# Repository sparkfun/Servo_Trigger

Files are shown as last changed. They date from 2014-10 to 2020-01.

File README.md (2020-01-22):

SparkFun Servo Trigger
========================================

SparkFun Servo Trigger

[*SparkFun Servo Trigger (WIG-13118)*](https://www.sparkfun.com/products/13118)

The SparkFun Servo Trigger is a small robotics board that simplifies the control of hobby RC servo motors. 
When an external switch or logic signal changes state, the Servo Trigger is able to tell an attached servo motor to move from position A to position B. 
To use the Servo Trigger, you simply connect a hobby servo and a switch, then use the on-board potentiometers to adjust the start/stop positions and the transition time. 

Repository Contents
-------------------
* **/Docs** -  Programming notes
* **/Firmware** - Example firmware for running the Servo Trigger
* **/Hardware** - All Eagle design files (.brd, .sch)
* **/Production** - Test bed files and production panel files

License Information
-------------------
The hardware is released under [Creative Commons ShareAlike 4.0 International](https://creativecommons.org/licenses/by-sa/4.0/).
The code is beerware; if you see me (or any other SparkFun employee) at the local, and you've found our code helpful, please buy us a round!

Distributed as-is; no warranty is given.

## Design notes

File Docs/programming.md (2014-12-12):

# Some Notes About TINY84 Tools.

*For notes regarding getting in and out of the device using a JTAGICE3, see the /firmware/tool-notes.txt.  This file explains some of the finer points of using a Tiny Programmer (PGM-11801) and AVRDude for field reprogramming, most likely of files that were created using the IDE.*

## Prepping the Target

If you've been developing with SWD mode, you need to clear that fuse before the ISP will be active again.

Do this by loading and running an application in AVRStudio, then select "debug->quit and reenable ISP" to exit the debug session.  Simply hitting the stop button leaves it in SWD mode, which is incompatible with 

## Getting the Tools

I was using a SparkFun Tiny Programmer (PGM-11801).  Win64 Drivers were downloaded from the product page.

I soldered a female 2x3 header to the bottom of the programmer, and a male 2x3 to the top of the Servo Trigger.  When they plug in together, the servo trigger board will point away from the USB plug, so as not to interfere mechanically.

I got AVRDude in the WinAVR bundle from [sourceforge](http://sourceforge.net/projects/winavr/files/WinAVR/).  The latest release should be linked near the top of the page.  There are some notes there that the install clobbers your path - this appears to have been fixed, and my path only got longer.

The AVRDude docs are [hosted at nongnu.org](http://www.nongnu.org/avrdude/user-manual).

### Testing

You can invoke AVRDude in interactive mode to demonstrate that everything is working.

	>avrdude -t -c usbtiny -p t84

From there, the `sig` commands should return the chip device ID, or `read flash 0 10` should read 10 bytes of flash.

### Programming

The moment you've been waiting for:

	>avrdude -c usbtiny -p t84 -e -U flash:w:GccApplication1.hex

This also does a verification readback of the chip.

GccApplication1.hex is simply the hex file produced in the /debug/ or /release/ folders of the AVRStudio project.

### Verifying

Use interactive mode to `read flash 0 1000`.  It'll dump a bunch of hex.  If it's all 0xff's something went wrong.  You can alternately verify flash using the programming command line, but replacing the `:w:` with a `:v:`.

### Fuses 

Should you need them, the fuses are available from avrdude.

You can get to the fuses using the following names for the memories (via the read or dump commands):

* lfuse - lower fuse byte.
* hfuse - higher fuse byte.
* efuse - extended fuse byte.

The device I was expreimenting with during the composition of this document has fuses of:

* lower: 0x7f
* upper: 0xdf
* extended: 0xff

The definition of the fuse bits is hidden in section 19.2 of the datasheet.  In short, these are mostly the defaults - notable enabled features are: SPI programming enabled, and external resonator enabled.

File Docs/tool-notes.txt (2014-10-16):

Developed using Atmel Studio 6 (6.2.1153) and the JTAGICE3 debug box.
---------------------------------

Atmel DebugWire is cool, but a hassle to get started with.  I'm spending too much time messing 
with it, trying to navigate everything, so I'm capturing the tricks and secrets here.

Navigation
----------

The first trick is that there are two panels that interact.

The first of these is part of the project file - the tab in the editor named after the project 
(IE tab "GccApplication1," no file extension).  
There's a sub-tab there makred "tool". 

The second of these is the Device Programming dialog (Ctrl+shift+P), or the button with the 
chip & lightning on it.

The project->tool tab lists the debugger/programmer, and specifies the interface it's using, ISP or DW.

Chips come with ISP enabled and DW disabled, plus some other settings like default clock source & brownout settings.

In order for the Device Programming dialog to work, we have to be in ISP mode.

The First Time
--------------

With a brand new chip, set the project page to use ISP.

Open the programming dialog.  
	Enable the interface, the read the voltage and device ID.
	Go to the fuses tab, select clock source, etc as needed.  
	If you're moving to use DW, enable that fuse.
	Program the fuses for the target - it may request a target power cycle.
	Close the dialog.

Set the project page to use DW.
Build the application.
Start debugging by loading the applicaton (F5)
	Debug as normal - pausing, single stepping, breakpoints all work as expected.

If you're going to rebuild/reload without reconfiguring the fuses, etc, you can just quit using the stop menu button.

If you're going to reconfigure the chip, you need to use the "debug->disable DebugWIRE and close" menu item.  
Otherwise, the chip stays in DW mode, and you'll get the  "Got 0xc0, expected 0x00" error message.

When You Get Stuck
------------------

It plays out like this: Yesterday you were debugging, today you start and decide to go and check the 
chip config in the programming dialog.  
Nothing works, and the error details contain  "Got 0xc0, expected 0x00."

The trick to unjam it - set the project to DW, and restart the debug session (F5).  Once loaded, use 
the "debug->disable DW and close" to get out.  Now ISP can get in.

One other fatal thing:
--------------------

I think I set the fuses for an external clock that isn't present on the board...I can't seem to 
get in at all...still conjuring a solution.

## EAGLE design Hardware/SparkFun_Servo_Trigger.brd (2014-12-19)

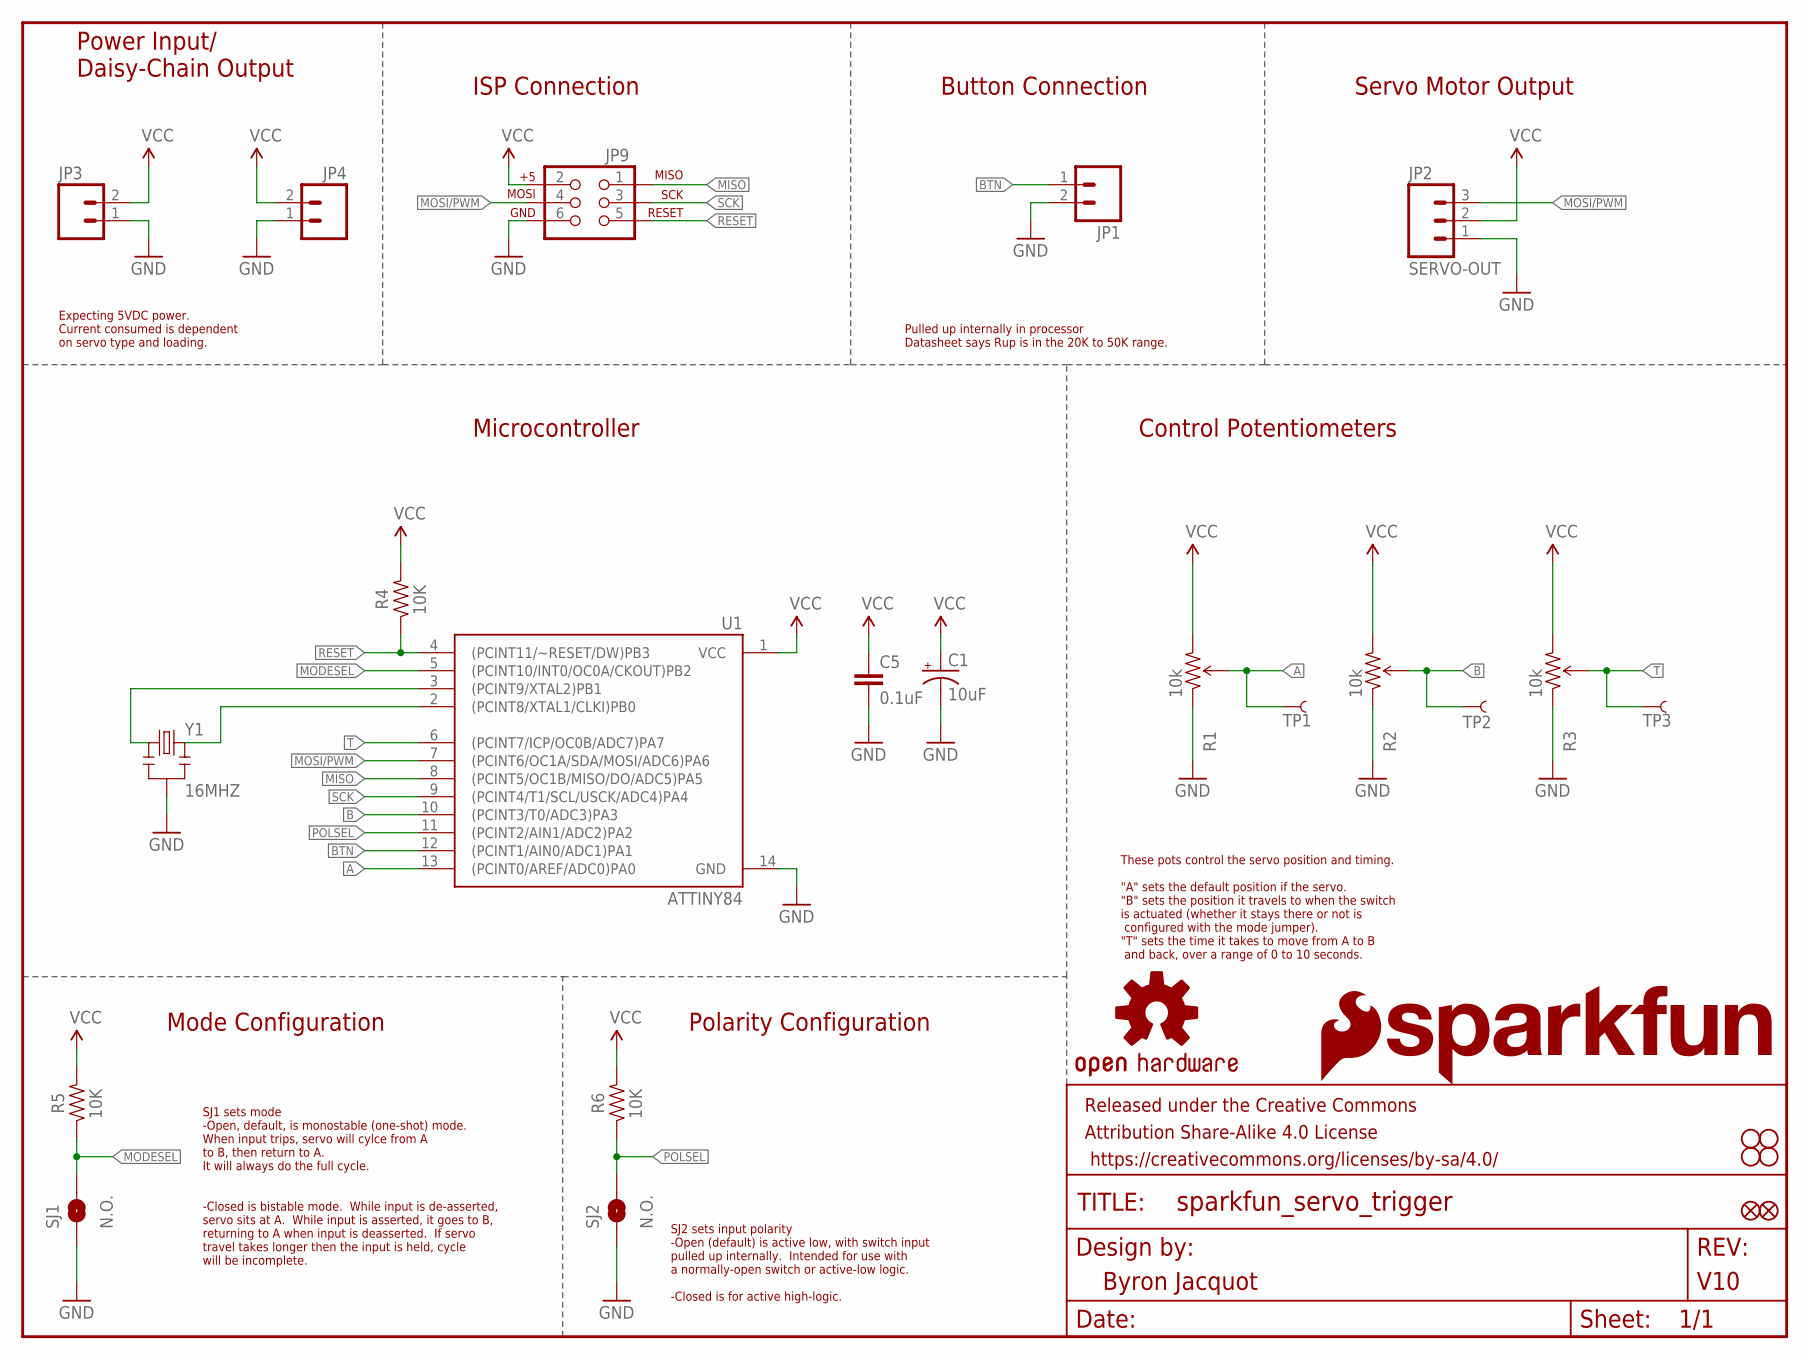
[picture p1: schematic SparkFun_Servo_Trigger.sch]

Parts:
C1: 10uF; EIA3216
C5: 0.1uF; 0603-CAP
FID1, FID2: FIDUCIAL1X2; FIDUCIAL-1X2
FRAME1: FRAME-LETTER; CREATIVE_COMMONS
JP1, JP3, JP4: M021X02_NO_SILK; 1X02_NO_SILK
JP2: SERVO-OUT; 1X03_NO_SILK
JP9: AVR_SPI_PRG_6PTH; 2X3
LOGO1: OSHW-LOGOM; OSHW-LOGO-M
LOGO2: SFE_LOGO_NAME.2_INCH; SFE_LOGO_NAME_.2
LOGO3: SFE_LOGO_FLAME.2_INCH; SFE_LOGO_FLAME_.2
R1, R2, R3: 10k; TRIMPOT_5MM
R4, R5, R6: 10K; 0603-RES
SJ1, SJ2: N.O.; PAD-JUMPER-2-NO_YES_SILK
STANDOFF1, STANDOFF2, STANDOFF3, STANDOFF4: STAND-OFF
TP1, TP2, TP3: TEST-POINT3X4; PAD.03X.04
U1: ATTINY84; SO14
Y1: 16MHZ; RESONATOR-SMD

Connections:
A: R1.B (WIPER), TP1.P$1, U1.13 ((PCINT0/AREF/ADC0)PA0)
B: R2.B (WIPER), TP2.P$1, U1.10 ((PCINT3/T0/ADC3)PA3)
BTN: JP1.1, U1.12 ((PCINT1/AIN0/ADC1)PA1)
GND: C1.C (-), C5.2, JP1.2, JP2.1, JP3.1, JP4.1, JP9.6, R1.A (CCW), R2.A (CCW), R3.A (CCW), SJ1.1, SJ2.1, U1.14 (GND), Y1.2
MISO: JP9.1, U1.8 ((PCINT5/OC1B/MISO/DO/ADC5)PA5)
MODESEL: R5.1, SJ1.2, U1.5 ((PCINT10/INT0/OC0A/CKOUT)PB2)
MOSI/PWM: JP2.3, JP9.4, U1.7 ((PCINT6/OC1A/SDA/MOSI/ADC6)PA6)
unnamed: U1.3 ((PCINT9/XTAL2)PB1), Y1.1
unnamed: U1.2 ((PCINT8/XTAL1/CLKI)PB0), Y1.3
POLSEL: R6.1, SJ2.2, U1.11 ((PCINT2/AIN1/ADC2)PA2)
RESET: JP9.5, R4.1, U1.4 ((PCINT11/~RESET/DW)PB3)
SCK: JP9.3, U1.9 ((PCINT4/T1/SCL/USCK/ADC4)PA4)
T: R3.B (WIPER), TP3.P$1, U1.6 ((PCINT7/ICP/OC0B/ADC7)PA7)
VCC: C1.A (+), C5.1, JP2.2, JP3.2, JP4.2, JP9.2, R1.C (CW), R2.C (CW), R3.C (CW), R4.2, R5.2, R6.2, U1.1 (VCC)

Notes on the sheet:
Power Input/ Daisy-Chain Output
ISP Connection
Control Potentiometers
Microcontroller
Button Connection
Servo Motor Output
Mode Configuration
Polarity Configuration
SJ1 sets mode -Open, default, is monostable (one-shot) mode. When input trips, servo will cylce from A to B, then return to A. It will always do the full cycle. -Closed is bistable mode. While input is de-asserted, servo sits at A. While input is asserted, it goes to B, returning to A when input is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
SJ2 sets input polarity -Open (default) is active low, with switch input pulled up internally. Intended for use with a normally-open switch or active-low logic. -Closed is for active high-logic.
Pulled up internally in processor Datasheet says Rup is in the 20K to 50K range.
Expecting 5VDC power. Current consumed is dependent on servo type and loading.
These pots control the servo position and timing. "A" sets the default position if the servo. "B" sets the position it travels to when the switch is actuated (whether it stays there or not is configured with the mode jumper). "T" sets the time it takes to move from A to B and back, over a range of 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

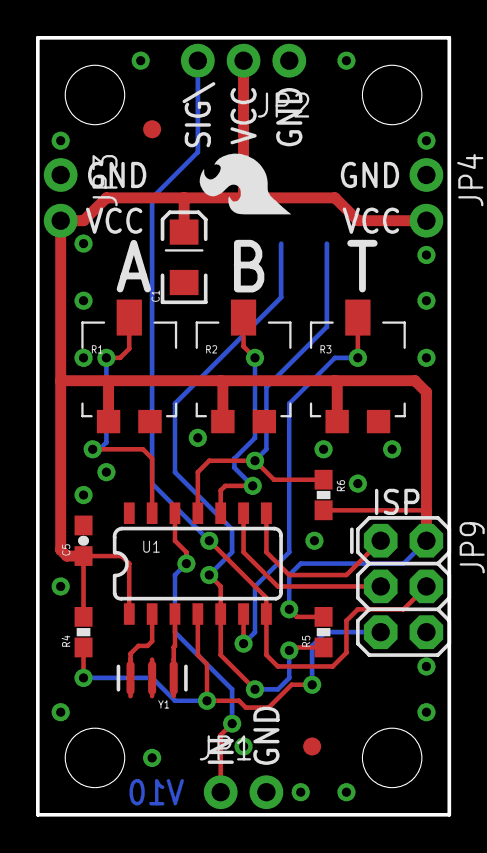
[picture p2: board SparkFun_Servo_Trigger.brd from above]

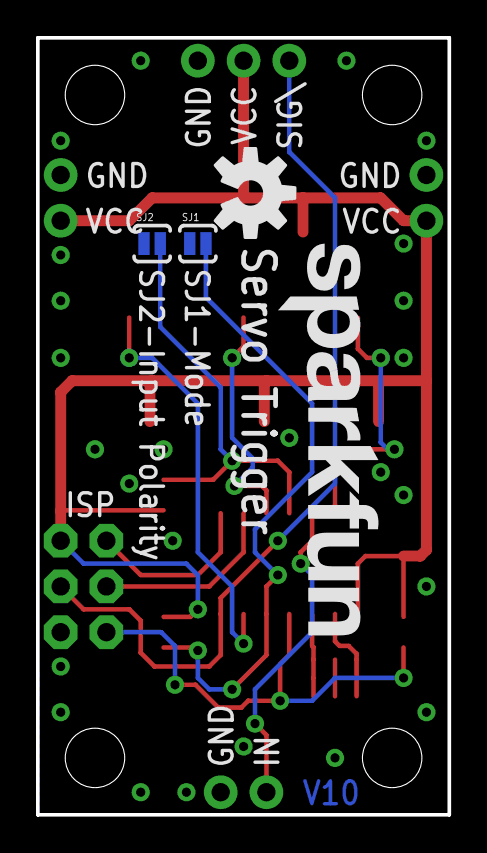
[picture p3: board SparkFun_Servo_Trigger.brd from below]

Board: 2 copper layers, 22.9 x 43.2 mm, 30 parts (7 on the bottom side), 14 nets.

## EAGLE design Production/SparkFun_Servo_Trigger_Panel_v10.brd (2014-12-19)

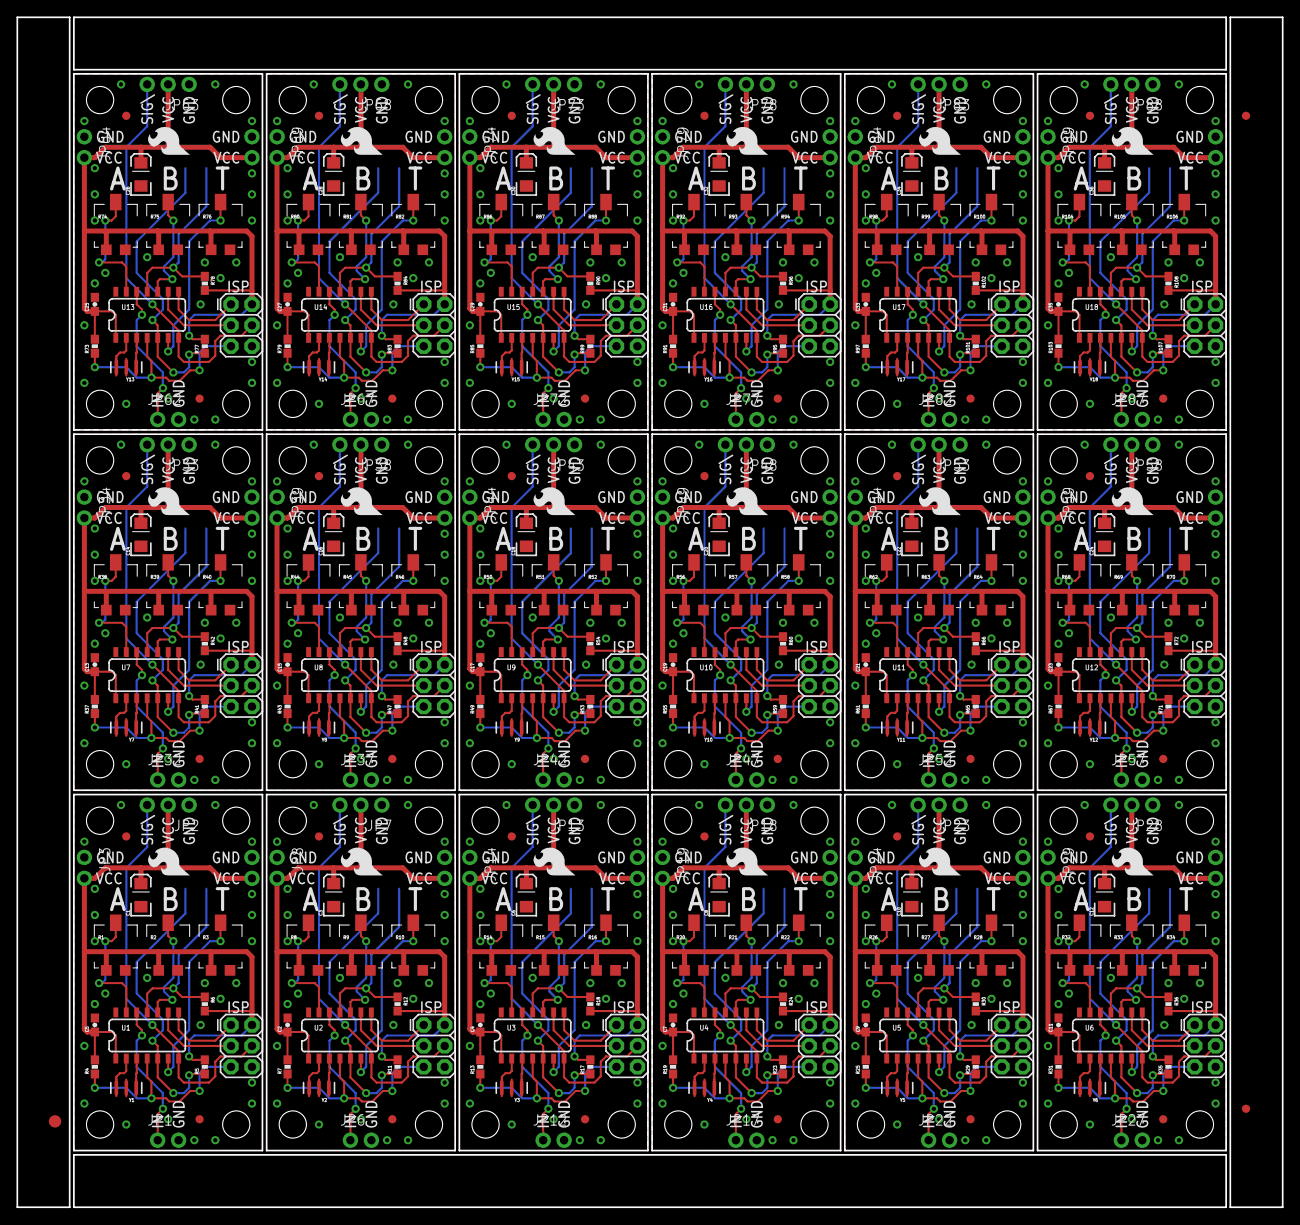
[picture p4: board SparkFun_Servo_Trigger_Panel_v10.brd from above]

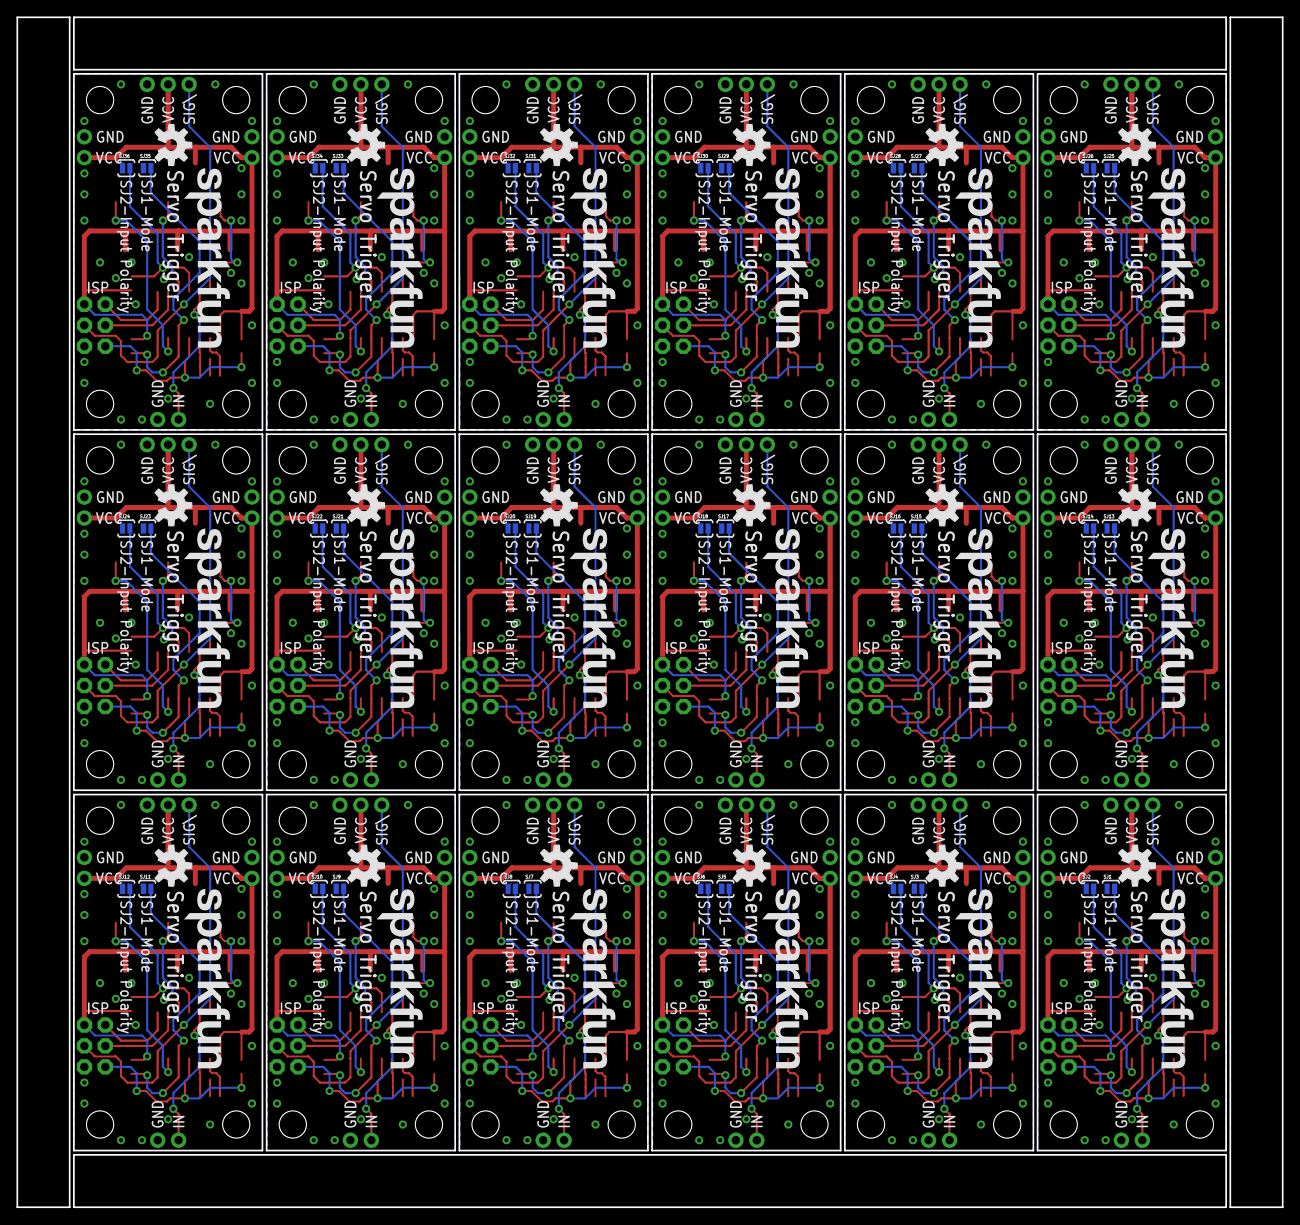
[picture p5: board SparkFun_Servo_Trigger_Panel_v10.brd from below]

Board: 2 copper layers, 153.4 x 144.3 mm, 525 parts (126 on the bottom side), 252 nets.

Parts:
C1, C3, C6, C8, C10, C12, C14, C16, C18, C20, C22, C24, C26, C28, C30, C32, C34, C36: 10uF; EIA3216
C2, C4, C5, C7, C9, C11, C13, C15, C17, C19, C21, C23, C25, C27, C29, C31, C33, C35: 0.1uF; 0603-CAP
E$1: FIDUCIAL-1.5X3
E$4, E$5: FIDUCIAL-1X2
FID1, FID2, FID3, FID4, FID5, FID6, FID7, FID8, FID9, FID10, FID11, FID12, FID13, FID14, FID15, FID16, FID17, FID18, FID19, FID20, FID21, FID22, FID23, FID24, FID25, FID26, FID27, FID28, FID29, FID30, FID31, FID32, FID33, FID34, FID35, FID36: FIDUCIAL1X2; FIDUCIAL-1X2
JP1, JP3, JP4, JP6, JP8, JP10, JP12, JP14, JP15, JP17, JP19, JP20, JP22, JP24, JP25, JP27, JP29, JP30, JP32, JP34, JP35, JP37, JP39, JP40, JP42, JP44, JP45, JP47, JP49, JP50, JP52, JP54, JP55, JP57, JP59, JP60, JP62, JP64, JP65, JP67, JP69, JP70, JP72, JP74, JP75, JP77, JP79, JP80, JP82, JP84, JP85, JP87, JP89, JP90: M021X02_NO_SILK; 1X02_NO_SILK
JP2, JP7, JP13, JP18, JP23, JP28, JP33, JP38, JP43, JP48, JP53, JP58, JP63, JP68, JP73, JP78, JP83, JP88: SERVO-OUT; 1X03_NO_SILK
JP5, JP9, JP11, JP16, JP21, JP26, JP31, JP36, JP41, JP46, JP51, JP56, JP61, JP66, JP71, JP76, JP81, JP86: 2X3
LOGO1, LOGO4, LOGO7, LOGO10, LOGO13, LOGO16, LOGO19, LOGO22, LOGO25, LOGO28, LOGO31, LOGO34, LOGO37, LOGO40, LOGO43, LOGO46, LOGO49, LOGO52: OSHW-LOGOM; OSHW-LOGO-M
LOGO2, LOGO5, LOGO8, LOGO11, LOGO14, LOGO17, LOGO20, LOGO23, LOGO26, LOGO29, LOGO32, LOGO35, LOGO38, LOGO41, LOGO44, LOGO47, LOGO50, LOGO53: SFE_LOGO_NAME.2_INCH; SFE_LOGO_NAME_.2
LOGO3, LOGO6, LOGO9, LOGO12, LOGO15, LOGO18, LOGO21, LOGO24, LOGO27, LOGO30, LOGO33, LOGO36, LOGO39, LOGO42, LOGO45, LOGO48, LOGO51, LOGO54: SFE_LOGO_FLAME.2_INCH; SFE_LOGO_FLAME_.2
R1, R2, R3, R8, R9, R10, R14, R15, R16, R20, R21, R22, R26, R27, R28, R32, R33, R34, R38, R39, R40, R44, R45, R46, R50, R51, R52, R56, R57, R58, R62, R63, R64, R68, R69, R70, R74, R75, R76, R80, R81, R82, R86, R87, R88, R92, R93, R94, R98, R99, R100, R104, R105, R106: 10k; TRIMPOT_5MM
R4, R5, R6, R7, R11, R12, R13, R17, R18, R19, R23, R24, R25, R29, R30, R31, R35, R36, R37, R41, R42, R43, R47, R48, R49, R53, R54, R55, R59, R60, R61, R65, R66, R67, R71, R72, R73, R77, R78, R79, R83, R84, R85, R89, R90, R91, R95, R96, R97, R101, R102, R103, R107, R108: 10K; 0603-RES
SJ1, SJ2, SJ3, SJ4, SJ5, SJ6, SJ7, SJ8, SJ9, SJ10, SJ11, SJ12, SJ13, SJ14, SJ15, SJ16, SJ17, SJ18, SJ19, SJ20, SJ21, SJ22, SJ23, SJ24, SJ25, SJ26, SJ27, SJ28, SJ29, SJ30, SJ31, SJ32, SJ33, SJ34, SJ35, SJ36: N.O.; PAD-JUMPER-2-NO_YES_SILK
STANDOFF1, STANDOFF2, STANDOFF3, STANDOFF4, STANDOFF5, STANDOFF6, STANDOFF7, STANDOFF8, STANDOFF9, STANDOFF10, STANDOFF11, STANDOFF12, STANDOFF13, STANDOFF14, STANDOFF15, STANDOFF16, STANDOFF17, STANDOFF18, STANDOFF19, STANDOFF20, STANDOFF21, STANDOFF22, STANDOFF23, STANDOFF24, STANDOFF25, STANDOFF26, STANDOFF27, STANDOFF28, STANDOFF29, STANDOFF30, STANDOFF31, STANDOFF32, STANDOFF33, STANDOFF34, STANDOFF35, STANDOFF36, STANDOFF37, STANDOFF38, STANDOFF39, STANDOFF40, STANDOFF41, STANDOFF42, STANDOFF43, STANDOFF44, STANDOFF45, STANDOFF46, STANDOFF47, STANDOFF48, STANDOFF49, STANDOFF50, STANDOFF51, STANDOFF52, STANDOFF53, STANDOFF54, STANDOFF55, STANDOFF56, STANDOFF57, STANDOFF58, STANDOFF59, STANDOFF60, STANDOFF61, STANDOFF62, STANDOFF63, STANDOFF64, STANDOFF65, STANDOFF66, STANDOFF67, STANDOFF68, STANDOFF69, STANDOFF70, STANDOFF71, STANDOFF72: STAND-OFF
TP1, TP2, TP3, TP4, TP5, TP6, TP7, TP8, TP9, TP10, TP11, TP12, TP13, TP14, TP15, TP16, TP17, TP18, TP19, TP20, TP21, TP22, TP23, TP24, TP25, TP26, TP27, TP28, TP29, TP30, TP31, TP32, TP33, TP34, TP35, TP36, TP37, TP38, TP39, TP40, TP41, TP42, TP43, TP44, TP45, TP46, TP47, TP48, TP49, TP50, TP51, TP52, TP53, TP54: TEST-POINT3X4; PAD.03X.04
U1, U2, U3, U4, U5, U6, U7, U8, U9, U10, U11, U12, U13, U14, U15, U16, U17, U18: ATTINY84; SO14
Y1, Y2, Y3, Y4, Y5, Y6, Y7, Y8, Y9, Y10, Y11, Y12, Y13, Y14, Y15, Y16, Y17, Y18: 16MHZ; RESONATOR-SMD

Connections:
A: R1.B, TP1.P$1, U1.13
A1: R8.B, TP4.P$1, U2.13
A2: R14.B, TP7.P$1, U3.13
A3: R20.B, TP10.P$1, U4.13
A4: R26.B, TP13.P$1, U5.13
A5: R32.B, TP16.P$1, U6.13
A6: R38.B, TP19.P$1, U7.13
A7: R44.B, TP22.P$1, U8.13
A8: R50.B, TP25.P$1, U9.13
A9: R56.B, TP28.P$1, U10.13
A10: R62.B, TP31.P$1, U11.13
A11: R68.B, TP34.P$1, U12.13
A12: R74.B, TP37.P$1, U13.13
A13: R80.B, TP40.P$1, U14.13
A14: R86.B, TP43.P$1, U15.13
A15: R92.B, TP46.P$1, U16.13
A16: R98.B, TP49.P$1, U17.13
A17: R104.B, TP52.P$1, U18.13
B: R2.B, TP2.P$1, U1.10
B1: R9.B, TP5.P$1, U2.10
B2: R15.B, TP8.P$1, U3.10
B3: R21.B, TP11.P$1, U4.10
B4: R27.B, TP14.P$1, U5.10
B5: R33.B, TP17.P$1, U6.10
B6: R39.B, TP20.P$1, U7.10
B7: R45.B, TP23.P$1, U8.10
B8: R51.B, TP26.P$1, U9.10
B9: R57.B, TP29.P$1, U10.10
B10: R63.B, TP32.P$1, U11.10
B11: R69.B, TP35.P$1, U12.10
B12: R75.B, TP38.P$1, U13.10
B13: R81.B, TP41.P$1, U14.10
B14: R87.B, TP44.P$1, U15.10
B15: R93.B, TP47.P$1, U16.10
B16: R99.B, TP50.P$1, U17.10
B17: R105.B, TP53.P$1, U18.10
BTN: JP1.1, U1.12
BTN1: JP6.1, U2.12
BTN2: JP12.1, U3.12
BTN3: JP17.1, U4.12
BTN4: JP22.1, U5.12
BTN5: JP27.1, U6.12
BTN6: JP32.1, U7.12
BTN7: JP37.1, U8.12
BTN8: JP42.1, U9.12
BTN9: JP47.1, U10.12
BTN10: JP52.1, U11.12
BTN11: JP57.1, U12.12
BTN12: JP62.1, U13.12
BTN13: JP67.1, U14.12
BTN14: JP72.1, U15.12
BTN15: JP77.1, U16.12
BTN16: JP82.1, U17.12
BTN17: JP87.1, U18.12
GND: C1.C, C5.2, JP1.2, JP2.1, JP3.1, JP4.1, JP9.6, R1.A, R2.A, R3.A, SJ1.1, SJ2.1, U1.14, Y1.2
GND1: C2.2, C3.C, JP5.6, JP6.2, JP7.1, JP8.1, JP10.1, R8.A, R9.A, R10.A, SJ3.1, SJ4.1, U2.14, Y2.2
GND2: C4.2, C6.C, JP11.6, JP12.2, JP13.1, JP14.1, JP15.1, R14.A, R15.A, R16.A, SJ5.1, SJ6.1, U3.14, Y3.2
GND3: C7.2, C8.C, JP16.6, JP17.2, JP18.1, JP19.1, JP20.1, R20.A, R21.A, R22.A, SJ7.1, SJ8.1, U4.14, Y4.2
GND4: C9.2, C10.C, JP21.6, JP22.2, JP23.1, JP24.1, JP25.1, R26.A, R27.A, R28.A, SJ9.1, SJ10.1, U5.14, Y5.2
GND5: C11.2, C12.C, JP26.6, JP27.2, JP28.1, JP29.1, JP30.1, R32.A, R33.A, R34.A, SJ11.1, SJ12.1, U6.14, Y6.2
GND6: C13.2, C14.C, JP31.6, JP32.2, JP33.1, JP34.1, JP35.1, R38.A, R39.A, R40.A, SJ13.1, SJ14.1, U7.14, Y7.2
GND7: C15.2, C16.C, JP36.6, JP37.2, JP38.1, JP39.1, JP40.1, R44.A, R45.A, R46.A, SJ15.1, SJ16.1, U8.14, Y8.2
GND8: C17.2, C18.C, JP41.6, JP42.2, JP43.1, JP44.1, JP45.1, R50.A, R51.A, R52.A, SJ17.1, SJ18.1, U9.14, Y9.2
GND9: C19.2, C20.C, JP46.6, JP47.2, JP48.1, JP49.1, JP50.1, R56.A, R57.A, R58.A, SJ19.1, SJ20.1, U10.14, Y10.2
GND10: C21.2, C22.C, JP51.6, JP52.2, JP53.1, JP54.1, JP55.1, R62.A, R63.A, R64.A, SJ21.1, SJ22.1, U11.14, Y11.2
GND11: C23.2, C24.C, JP56.6, JP57.2, JP58.1, JP59.1, JP60.1, R68.A, R69.A, R70.A, SJ23.1, SJ24.1, U12.14, Y12.2
GND12: C25.2, C26.C, JP61.6, JP62.2, JP63.1, JP64.1, JP65.1, R74.A, R75.A, R76.A, SJ25.1, SJ26.1, U13.14, Y13.2
GND13: C27.2, C28.C, JP66.6, JP67.2, JP68.1, JP69.1, JP70.1, R80.A, R81.A, R82.A, SJ27.1, SJ28.1, U14.14, Y14.2
GND14: C29.2, C30.C, JP71.6, JP72.2, JP73.1, JP74.1, JP75.1, R86.A, R87.A, R88.A, SJ29.1, SJ30.1, U15.14, Y15.2
GND15: C31.2, C32.C, JP76.6, JP77.2, JP78.1, JP79.1, JP80.1, R92.A, R93.A, R94.A, SJ31.1, SJ32.1, U16.14, Y16.2
GND16: C33.2, C34.C, JP81.6, JP82.2, JP83.1, JP84.1, JP85.1, R98.A, R99.A, R100.A, SJ33.1, SJ34.1, U17.14, Y17.2
GND17: C35.2, C36.C, JP86.6, JP87.2, JP88.1, JP89.1, JP90.1, R104.A, R105.A, R106.A, SJ35.1, SJ36.1, U18.14, Y18.2
MISO: JP9.1, U1.8
MISO1: JP5.1, U2.8
MISO2: JP11.1, U3.8
MISO3: JP16.1, U4.8
MISO4: JP21.1, U5.8
MISO5: JP26.1, U6.8
MISO6: JP31.1, U7.8
MISO7: JP36.1, U8.8
MISO8: JP41.1, U9.8
MISO9: JP46.1, U10.8
MISO10: JP51.1, U11.8
MISO11: JP56.1, U12.8
MISO12: JP61.1, U13.8
MISO13: JP66.1, U14.8
MISO14: JP71.1, U15.8
MISO15: JP76.1, U16.8
MISO16: JP81.1, U17.8
MISO17: JP86.1, U18.8
MODESEL: R5.1, SJ1.2, U1.5
MODESEL1: R11.1, SJ3.2, U2.5
MODESEL2: R17.1, SJ5.2, U3.5
MODESEL3: R23.1, SJ7.2, U4.5
MODESEL4: R29.1, SJ9.2, U5.5
MODESEL5: R35.1, SJ11.2, U6.5
MODESEL6: R41.1, SJ13.2, U7.5
MODESEL7: R47.1, SJ15.2, U8.5
MODESEL8: R53.1, SJ17.2, U9.5
MODESEL9: R59.1, SJ19.2, U10.5
MODESEL10: R65.1, SJ21.2, U11.5
MODESEL11: R71.1, SJ23.2, U12.5
MODESEL12: R77.1, SJ25.2, U13.5
MODESEL13: R83.1, SJ27.2, U14.5
MODESEL14: R89.1, SJ29.2, U15.5
MODESEL15: R95.1, SJ31.2, U16.5
MODESEL16: R101.1, SJ33.2, U17.5
MODESEL17: R107.1, SJ35.2, U18.5
MOSI/PWM: JP2.3, JP9.4, U1.7
MOSI/PWM1: JP5.4, JP7.3, U2.7
MOSI/PWM2: JP11.4, JP13.3, U3.7
MOSI/PWM3: JP16.4, JP18.3, U4.7
MOSI/PWM4: JP21.4, JP23.3, U5.7
MOSI/PWM5: JP26.4, JP28.3, U6.7
MOSI/PWM6: JP31.4, JP33.3, U7.7
MOSI/PWM7: JP36.4, JP38.3, U8.7
MOSI/PWM8: JP41.4, JP43.3, U9.7
MOSI/PWM9: JP46.4, JP48.3, U10.7
MOSI/PWM10: JP51.4, JP53.3, U11.7
MOSI/PWM11: JP56.4, JP58.3, U12.7
MOSI/PWM12: JP61.4, JP63.3, U13.7
MOSI/PWM13: JP66.4, JP68.3, U14.7
MOSI/PWM14: JP71.4, JP73.3, U15.7
MOSI/PWM15: JP76.4, JP78.3, U16.7
MOSI/PWM16: JP81.4, JP83.3, U17.7
MOSI/PWM17: JP86.4, JP88.3, U18.7
unnamed: U2.3, Y2.1
unnamed: U2.2, Y2.3
unnamed: U1.3, Y1.1
unnamed: U1.2, Y1.3
unnamed: U3.3, Y3.1
unnamed: U3.2, Y3.3
unnamed: U4.3, Y4.1
unnamed: U4.2, Y4.3
unnamed: U5.3, Y5.1
unnamed: U5.2, Y5.3
unnamed: U6.3, Y6.1
unnamed: U6.2, Y6.3
unnamed: U7.3, Y7.1
unnamed: U7.2, Y7.3
unnamed: U8.3, Y8.1
unnamed: U8.2, Y8.3
unnamed: U9.3, Y9.1
unnamed: U9.2, Y9.3
unnamed: U10.3, Y10.1
unnamed: U10.2, Y10.3
unnamed: U11.3, Y11.1
unnamed: U11.2, Y11.3
unnamed: U12.3, Y12.1
unnamed: U12.2, Y12.3
unnamed: U13.3, Y13.1
unnamed: U13.2, Y13.3
unnamed: U14.3, Y14.1
unnamed: U14.2, Y14.3
unnamed: U15.3, Y15.1
unnamed: U15.2, Y15.3
unnamed: U16.3, Y16.1
unnamed: U16.2, Y16.3
unnamed: U17.3, Y17.1
unnamed: U17.2, Y17.3
unnamed: U18.3, Y18.1
unnamed: U18.2, Y18.3
POLSEL: R6.1, SJ2.2, U1.11
POLSEL1: R12.1, SJ4.2, U2.11
POLSEL2: R18.1, SJ6.2, U3.11
POLSEL3: R24.1, SJ8.2, U4.11
POLSEL4: R30.1, SJ10.2, U5.11
POLSEL5: R36.1, SJ12.2, U6.11
POLSEL6: R42.1, SJ14.2, U7.11
POLSEL7: R48.1, SJ16.2, U8.11
POLSEL8: R54.1, SJ18.2, U9.11
POLSEL9: R60.1, SJ20.2, U10.11
POLSEL10: R66.1, SJ22.2, U11.11
POLSEL11: R72.1, SJ24.2, U12.11
POLSEL12: R78.1, SJ26.2, U13.11
POLSEL13: R84.1, SJ28.2, U14.11
POLSEL14: R90.1, SJ30.2, U15.11
POLSEL15: R96.1, SJ32.2, U16.11
POLSEL16: R102.1, SJ34.2, U17.11
POLSEL17: R108.1, SJ36.2, U18.11
RESET: JP9.5, R4.1, U1.4
RESET1: JP5.5, R7.1, U2.4
RESET2: JP11.5, R13.1, U3.4
RESET3: JP16.5, R19.1, U4.4
RESET4: JP21.5, R25.1, U5.4
RESET5: JP26.5, R31.1, U6.4
RESET6: JP31.5, R37.1, U7.4
RESET7: JP36.5, R43.1, U8.4
RESET8: JP41.5, R49.1, U9.4
RESET9: JP46.5, R55.1, U10.4
RESET10: JP51.5, R61.1, U11.4
RESET11: JP56.5, R67.1, U12.4
RESET12: JP61.5, R73.1, U13.4
RESET13: JP66.5, R79.1, U14.4
RESET14: JP71.5, R85.1, U15.4
RESET15: JP76.5, R91.1, U16.4
RESET16: JP81.5, R97.1, U17.4
RESET17: JP86.5, R103.1, U18.4
SCK: JP9.3, U1.9
SCK1: JP5.3, U2.9
SCK2: JP11.3, U3.9
SCK3: JP16.3, U4.9
SCK4: JP21.3, U5.9
SCK5: JP26.3, U6.9
SCK6: JP31.3, U7.9
SCK7: JP36.3, U8.9
SCK8: JP41.3, U9.9
SCK9: JP46.3, U10.9
SCK10: JP51.3, U11.9
SCK11: JP56.3, U12.9
SCK12: JP61.3, U13.9
SCK13: JP66.3, U14.9
SCK14: JP71.3, U15.9
SCK15: JP76.3, U16.9
SCK16: JP81.3, U17.9
SCK17: JP86.3, U18.9
T: R3.B, TP3.P$1, U1.6
T1: R10.B, TP6.P$1, U2.6
T2: R16.B, TP9.P$1, U3.6
T3: R22.B, TP12.P$1, U4.6
T4: R28.B, TP15.P$1, U5.6
T5: R34.B, TP18.P$1, U6.6
T6: R40.B, TP21.P$1, U7.6
T7: R46.B, TP24.P$1, U8.6
T8: R52.B, TP27.P$1, U9.6
T9: R58.B, TP30.P$1, U10.6
T10: R64.B, TP33.P$1, U11.6
T11: R70.B, TP36.P$1, U12.6
T12: R76.B, TP39.P$1, U13.6
T13: R82.B, TP42.P$1, U14.6
T14: R88.B, TP45.P$1, U15.6
T15: R94.B, TP48.P$1, U16.6
T16: R100.B, TP51.P$1, U17.6
T17: R106.B, TP54.P$1, U18.6
VCC: C1.A, C5.1, JP2.2, JP3.2, JP4.2, JP9.2, R1.C, R2.C, R3.C, R4.2, R5.2, R6.2, U1.1
VCC1: C2.1, C3.A, JP5.2, JP7.2, JP8.2, JP10.2, R7.2, R8.C, R9.C, R10.C, R11.2, R12.2, U2.1
VCC2: C4.1, C6.A, JP11.2, JP13.2, JP14.2, JP15.2, R13.2, R14.C, R15.C, R16.C, R17.2, R18.2, U3.1
VCC3: C7.1, C8.A, JP16.2, JP18.2, JP19.2, JP20.2, R19.2, R20.C, R21.C, R22.C, R23.2, R24.2, U4.1
VCC4: C9.1, C10.A, JP21.2, JP23.2, JP24.2, JP25.2, R25.2, R26.C, R27.C, R28.C, R29.2, R30.2, U5.1
VCC5: C11.1, C12.A, JP26.2, JP28.2, JP29.2, JP30.2, R31.2, R32.C, R33.C, R34.C, R35.2, R36.2, U6.1
VCC6: C13.1, C14.A, JP31.2, JP33.2, JP34.2, JP35.2, R37.2, R38.C, R39.C, R40.C, R41.2, R42.2, U7.1
VCC7: C15.1, C16.A, JP36.2, JP38.2, JP39.2, JP40.2, R43.2, R44.C, R45.C, R46.C, R47.2, R48.2, U8.1
VCC8: C17.1, C18.A, JP41.2, JP43.2, JP44.2, JP45.2, R49.2, R50.C, R51.C, R52.C, R53.2, R54.2, U9.1
VCC9: C19.1, C20.A, JP46.2, JP48.2, JP49.2, JP50.2, R55.2, R56.C, R57.C, R58.C, R59.2, R60.2, U10.1
VCC10: C21.1, C22.A, JP51.2, JP53.2, JP54.2, JP55.2, R61.2, R62.C, R63.C, R64.C, R65.2, R66.2, U11.1
VCC11: C23.1, C24.A, JP56.2, JP58.2, JP59.2, JP60.2, R67.2, R68.C, R69.C, R70.C, R71.2, R72.2, U12.1
VCC12: C25.1, C26.A, JP61.2, JP63.2, JP64.2, JP65.2, R73.2, R74.C, R75.C, R76.C, R77.2, R78.2, U13.1
VCC13: C27.1, C28.A, JP66.2, JP68.2, JP69.2, JP70.2, R79.2, R80.C, R81.C, R82.C, R83.2, R84.2, U14.1
VCC14: C29.1, C30.A, JP71.2, JP73.2, JP74.2, JP75.2, R85.2, R86.C, R87.C, R88.C, R89.2, R90.2, U15.1
VCC15: C31.1, C32.A, JP76.2, JP78.2, JP79.2, JP80.2, R91.2, R92.C, R93.C, R94.C, R95.2, R96.2, U16.1
VCC16: C33.1, C34.A, JP81.2, JP83.2, JP84.2, JP85.2, R97.2, R98.C, R99.C, R100.C, R101.2, R102.2, U17.1
VCC17: C35.1, C36.A, JP86.2, JP88.2, JP89.2, JP90.2, R103.2, R104.C, R105.C, R106.C, R107.2, R108.2, U18.1

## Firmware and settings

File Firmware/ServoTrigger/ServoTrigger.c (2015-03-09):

/*
 ServoTrigger.c
 
 Created: 7/3/2014 3:43:10 PM
 Author: byron.jacquot
 
 The Servo Trigger is a small board you can use to implement simple control 
 over hobby RC servos.  When an external switch or logic signal changes 
 state, the servo trigger causes the servo motor to move from  position A 
 to position B.  You also specify the time that the servo takes to make 
 the transition. 
 
 The code is designed to function primarily in the interrupt service routine
 for PWM1.  PWM hardware is configured to call the ISR at the start of the cycle
 when the output gets set high.  It then calculates and sets the pulse 
 width, and refreshes the ADC inputs.
 
 The main loop of the code is rather simple.  It sets up in I/O and
 PWM, then allows the interrupt to run, and puts the processor to 
 sleep in between.
 
 DEVELOPMENT TOOLS:
 This code was developed in Atmel Studio 6.2.1153.
 The build should also be compatible with avr-gcc & avrdude on the command line.
 
 BUILDING & CONFIGURATION:
 There are more possible state machines than can fit in memory all at once.
 2 FSMs can be present at a time - selected using the MODE solder jumper on the back
 of the PCB.  They are known as FSMA (jumper cleared - default) and FSMB (jumper soldered).
 
 The FSMs are selected by defining compile-time macros in the build scripts. 
 To change functions, find the -D directives, and set them to the names of the
 desired functions. 
 In AVRStudio, this is in the project tab->toolchain->AVR/GNU C compiler->symbols dialog. 
 In the command-line AVR-GCC, it's in the *.c->*.o rule in the makefile.
 
 You can select the FSMs for the two slots by changing the definition of the "FSMA" and
 "FSMB" macros.  These macros should be set to the name of the FSM function for the desired slot.
 There are several candidate FSM names:
  - bistableFSM
  - oneshotFSM
  - ctpFSM
  - togglingFSM
  - astableFSM
 
 See the product documentation for more details about each FSM.
 
 All of these FSMs are implemented in the source file - rather than building a bunch of 
 convoluted macros to include the right functions, we're taking advantage of the 
 linker-elision feature of GCC - functions that are never called will be omitted from the 
 output - you'll see the names in the "discarded sections" of the *.MAP file.  It's very
 dependent of compiling and linking with the right flags set.
 See this link for more info: https://gcc.gnu.org/ml/gcc-help/2003-08/msg00128.html
 
 
 If you want to implement your own FSM, there are a few things to know:
 - First, the FSMs operate on a phasor value to implement the ramp between A and B.
   The FSM function is invoked at the start of every PWM cycle, and it needs to 
   calculate and update the phasor value.  The phasor is 16-bits, and normalized 
   such that position A is always 0x0, and B is 0xffff.  The FSM updates the phasor.
 - The phasor will be translated for the actual A & B settings before it's applied.
 - There are helper routines:
     - calcDelta calculates how big a step is needed for a given setting of T
     - calcNextPhasor adds or subtracts the delta, and returns true when the phasor 
        reaches the end of the transit.
     - scalePhasor translates the 0 to 0xffff value to pulse width, in microseconds.
 
 */ 

#include <avr/io.h>
#include <avr/interrupt.h>
#include <avr/sleep.h>
#include <stdint.h>
#include <stdbool.h>

/* constant declarations */

// constants for the hardware interfaces
// Pots for positions A, B and time T.
// Numbers are ADC channels, not pins
static const uint8_t POTA_CHAN = 0;
static const uint8_t POTB_CHAN = 3;
static const uint8_t POTT_CHAN = 7;

// Pins for configuration solder jumpers
// "_A_" means in port A, "_B_" means in port B.
static const uint8_t POLSEL_A_MASK = 0x04;
static const uint8_t MODESEL_B_MASK = 0x04;

// Input pin for switch or trigger
// "_A_" means in port A
static const uint8_t TRIG_PIN_A_MASK = 0x02;

// Timing & ramp gen constants
// Pulse width = PWM_MIN_USEC + PWM_RANGE_USEC
// some servos have a wider range than others - 1 to 2 msec is safe for all tested so far.
// .7 to 2.3 msec will drive some farther, but will make others very unhappy, possibly grinding gears.

#ifdef SAFERANGE
// Some servos are *very* unhappy if pulses leave the 1 to 2 mSec range.  
// SAFERANGE constrains pulses to that range.
static const int32_t PWM_MIN_USEC   = 1000; // narrowest pulse is 1000 usec
static const int32_t PWM_RANGE_USEC = 1000; // diff between min and max PWM pulses.
#else
// some servos are less fragile/critical - if you want shorter/wider pulses, 
// you can enable these and adjust the values
static const int32_t PWM_MIN_USEC   = 700; // narrowest pulse is 700 usec
static const int32_t PWM_RANGE_USEC = 1600; // diff between min and max PWM pulses.
#endif


static const int32_t ADC_MAX        = 0x0000ffff; // ADC values are left-justified into 16-bits
static const int32_t PHASOR_MAX     = 0x0000ffff; // Phasor counts from 0 to 0xffff

// declare some constants for calculations
//
// Table of timing constants.
// These are looked up and added to the phasor on each pulse ISR.
// They are indexed & interpolated using the T pot.
//
// Each value was calc'd using the spreadsheet: translation.ods
//
// the formula per entry is
// value = PHASOR_MAX/pwm freq in Hz/desired time
// ie: increment = 0xffff/50/travel time
//
// Table is 17 entries long so we can do linear interpolation between
// the N and N+1th entries, indexed using 4 MSBs of T value, interpolated
// using the next 4 bits.
static const int16_t timelut[17] =
{
    437,  583,   749,   1049,
    1311, 1748,  2185,  2621,
    3277, 4369,  5243,  6554,
    8738, 10923, 13107, 16384,
    26214
};


/* Structure definitions */

// All the FSMs use the same group of states - some may not use all states.
typedef enum state
{
	eIDLE = 0,
	eATOB,
	eATTOP,
	eBTOA,
	eWAIT_TO_RESET	
}state;

// status encapsulates what would otherwise be global variables.
typedef struct status 
{
	int32_t a; // latest ADC value for A pot
	int32_t b; // latest ADC value for B pot
	int32_t t; // latest ADC value for T pot 
	
	bool  input; // is input asserted?  (accounting for input polarity setting)
	
    
	bool  mode;  // stores mode jumper config
	bool  input_polarity; // stores input polarity jumper config
	
	state st;  // currently active state of FSM
	
	int32_t phasor; // counts 0 to 0xffff - needs to be singed to catch overflow
	bool    rising; // are we rising or falling?
	
	int32_t us_val; // how many microseconds to add to the PWM pulse?
	
}status;

/* Structure declarations*/

status     current_status;


/*
	calcDelta()

	Calculate how far to step in each increment, and return the step size.
	It's based on the reading of the T pot.
	MS nybble indexes LUT value.
	Also reads the next adjacent LUT value, then uses next nybble to 
	fo linear interoplation between them.
*/
int16_t calcDelta()
{
	// time reading is 12 bits, formatted into the top of 
	// a 16-bit value.
	// We'll use the 4 MSBs to look up a time value,
	// and the next 4 to do linear interpolation between it and the next value.

	uint8_t idx = current_status.t >> 12;
	int16_t val = timelut[idx];
	
	// Calc window between this and next value
	volatile int16_t window = timelut[idx+1] - timelut[idx];

	// split that window into 16 chunks
	window >>= 4;  // IE: divide by 16
	
	// and take the number of chunks as determined by the next 4 bits
	window *= ((current_status.t & 0x00000f00) >> 8);

	return val + window;

}


/*
	bool calcNextPhasor(int16_t increment)

    This calculates the value of the phasor.
    The phasor is range constrained:
      - it always goes from 0 to 0xffff (PHASOR_MAX)
      - it always increases on the A->B traverse
      - it always decreases on the B->A traverse
      - it sits at the endpoints (0 or 0xffff) when in the static positions

    This leaves us some resolution, so really slow transitions atill slowly crawl 
    along, and really quick ones

    The trick is that it will be scaled based on the pot settings before being applied.

    Returns true when segment overflows, to advance FSM.
*/
bool calcNextPhasor(int16_t increment)
{
	if(current_status.rising)
	{
		current_status.phasor += increment;
	}
	else
	{
		current_status.phasor -= increment;
	}
	
	// check for over/underflow indicating end of segment reached.
	// If so, truncate & return...
	if(current_status.phasor > PHASOR_MAX)
	{
		current_status.phasor = PHASOR_MAX;
		return true;		
	}
	else if(current_status.phasor < 0)
	{
		current_status.phasor = 0;
		return true;		
	}
	
	return false;
}

/*
    int16_t scalePhasor()

    This routine scales the phasor into the proper range.
    The phasor always goes from A to B by covering the 0 to 0xffff range
    But A and B may by nearer to each other than that
    and B might even be less than A, reversing things overall.
    This routine centralizes that translation.
*/
int16_t scalePhasor()
{
	int32_t range;
	int32_t offset;
	
	int32_t   result;

	// a, b are 16-bit unsigned values	
	// range and offset are 32-bit signed.
    // When a > b, range is negative
	// thus the ultimate result will be subtracted from the offset.
	range = current_status.b - current_status.a;
	offset = current_status.a;
	
	//Scale range and offset into uSec values.
	range = (range * PWM_RANGE_USEC)/ADC_MAX;
	offset = (offset * PWM_RANGE_USEC)/ADC_MAX;
		
	// scale phasor into range
	result = (current_status.phasor * range)/PHASOR_MAX;
		
	//add on offset
    // (or subtract, if a > b)
	result += offset;

	return result;
}

/* void bistableFSM()

    This FSM sits in bottom state (A) waiting for switch to close.
	When it closes, it transits to B, taking time T.
	It stays in B until the switch opens.
	It then transits back to A, again taking time T.

    On every invocation, it will update the microsecond value in current_status.
*/
void bistableFSM()
{
	int16_t delta;
	
	delta = calcDelta();
	
	switch(current_status.st)
	{
		case eIDLE:
		{
			// Advance when we see the switch actuate
			if(current_status.input == true)
			{
				current_status.st = eATOB;
				current_status.rising         = true;
			}
		}
		break;
		case eATOB:
		{
            // Switch released early
			if(current_status.input == false)
			{
				current_status.st = eBTOA;
				current_status.rising         = false;				
			}
			
			// climbing up to b
			if( calcNextPhasor(delta) )
			{
				current_status.st = eATTOP;
			}
		}
		break;
		case eATTOP:
		{
            // waiting for switch release
			if(current_status.input == false)
			{
				current_status.st = eBTOA;
				current_status.rising         = false;
			}
		}
		break;
		case eBTOA:
		{
            // Switch re-closed before reaching A
			if(current_status.input == true)
			{
				current_status.st = eATOB;
				current_status.rising         = true;
			}
			
			// dropping down to A
			if( calcNextPhasor(delta) )
			{
				current_status.st = eIDLE;
			}
		}
		break;
		default:
		{
			// TODO: better fix?
			// debugger catch for invalid states
			while(1);
		}
	}
	
	current_status.us_val =  scalePhasor();
	
}

/* void oneshotFSM()

    This FSM sits in idle state (A) waiting for switch to close.
    When it closes, it does a complete cycle A-to-B-to-A, then waits for switch release.

    On every invocation, it will update the microsecond value in current_status.
*/
void oneshotFSM()
{
	int16_t delta;
	
	delta = calcDelta();
	
	switch(current_status.st)
	{
		case eIDLE:
		{
			// Advance when we see the switch actuate
			if(current_status.input == true)
			{
				current_status.st = eATOB;
				current_status.rising         = true;
			}
		}
		break;
		case eATOB:
		{
			// climbing up to b
			// only quits when it gets there - ignores switch
			if( calcNextPhasor(delta) )
			{
				current_status.st = eBTOA;
				current_status.rising         = false;
			}
		}
		break;
		case eATTOP:
		{
			// we shouldn't actually land here,
			// provide proper action in case we somehow do.
			current_status.st = eBTOA;
			current_status.rising         = false;
		}
		break;
		case eBTOA:
		{
			// dropping down to A
			// only quits when it gets there - ignores switch
			if( calcNextPhasor(delta) )
			{
				current_status.st = eWAIT_TO_RESET;
			}
		}
		break;
		case eWAIT_TO_RESET:
		{
			// If the switch is still held
			// wait for it's release here
			if(!current_status.input)
			{
				current_status.st = eIDLE;
			}
			
		}
		break;
		default:
		{
			// TODO: better fix?
			// debugger catch for invalid states
			while(1);
		}
	}
	
	current_status.us_val =  scalePhasor();
	
}

/* bool edgeDetect()

    A simple edge detector for the ctpFSM.
    Other FSMs have been level sensitive

*/
bool edgeDetect()
{
    static uint8_t deb_count = 0;

    if(current_status.input == 0)
    {
        deb_count = 0;
    }
    else if(current_status.input == 1)
    {
        
        // increment counter
        deb_count++;
                
        if(deb_count == 2)
        {
            // we call 2 in a row a rising edge
            return true;            
        }
        else if(deb_count >= 3)
        {
            // make it stick at 3 so it can't overflow
            deb_count = 3;
        }
    }

    return false;
}


/* void ctpFSM()

    Custom FSM for CTP's cuckoo bellows project.

    This FSM sits in idle state (A) waiting for switch to close.
    This is similar to the oneshotFSM, but differs a bit in the retriggering behavior.
    
    When switch closes, it does a complete cycle A-to-B.
    It then begins a B-to-A, but watches for additional switch closures.  If found,
    it will jump back to the A-to-B state.  This makes it more responsive to repeated 
    switch actuations, because it doesn't need to complete the B-to-A cycle.

    On every invocation, it will update the microsecond value in current_status.
*/
void ctpFSM()
{
	int16_t delta;
	
	delta = calcDelta();
	
    bool edge = edgeDetect();
    
	switch(current_status.st)
	{
		case eIDLE:
		{
			// Advance when we see the switch actuate
			if(edge)
			{
				current_status.st = eATOB;
				current_status.rising         = true;
			}
		}
		break;
		case eATOB:
		{
			// climbing up to b
			// only quits when it gets there - ignores switch
			if( calcNextPhasor(delta) )
			{
                // It didn't do so well when it jumped straight to BTOA...
				current_status.st = eATTOP;
				current_status.rising         = false;
			}
		}
		break;
		case eATTOP:
		{
			// we shouldn't actually land here,
			// provide proper action in case we somehow do.
			current_status.st = eBTOA;
			current_status.rising         = false;
		}
		break;
		case eBTOA:
		{
			// dropping down to A,
            // but if we see new edge, return to B.
			if(edge)
			{
    			current_status.st     = eATOB;
    			current_status.rising = true;
			}
			if( calcNextPhasor(delta) )
			{
				current_status.st = eIDLE;
			}
		}
		break;
		default:
		{
			// TODO: better fix?
			// debugger catch for invalid states
			while(1);
		}
	}
	
	current_status.us_val =  scalePhasor();
	
}

/* void togglingFSM()

    ThisFSM will toggle between A and B each time the input changes.
    
    Unlike other FSMs, it takes 2 actuations to make a complete cycle.
    
    It might be useful with continuous rotation servos, which could drive 
    back and forth, changing direction with each input.  
    Automated camera slider, maybe?
    */
void togglingFSM()
{
    int16_t delta;
    
    delta = calcDelta();
    
    bool edge = edgeDetect();
    
    switch(current_status.st)
    {
        case eIDLE: 
        {
            // Advance when we see the switch actuate
            if(edge)
            {
                current_status.st = eATOB;
                current_status.rising         = true;
            }
        }
        break;
        case eATOB:
        {
            // rising to B,
            // but if we see new edge, return to A.
            if(edge)
            {
                current_status.st     = eBTOA;
                current_status.rising = false;
            }
            if( calcNextPhasor(delta) )
            {
                current_status.st = eATTOP;
            }
        }
        break;
        case eATTOP:
        {
            // Advance when we see the switch actuate
            if(edge)
            {
                current_status.st = eBTOA;
                current_status.rising         = false;
            }
        }
        break;
        case eBTOA:
        {
            // dropping down to A,
            // but if we see new edge, return to B.
            if(edge)
            {
                current_status.st     = eATOB;
                current_status.rising = true;
            }
            if( calcNextPhasor(delta) )
            {
                current_status.st = eIDLE;
            }
        }
        break;
        default:
        {
            // TODO: better fix?
            // debugger catch for invalid states
            while(1);
        }
    }
    
    current_status.us_val =  scalePhasor();
    
}

/* void astableFSM()
  astable - runs back & forth while switch is held
*/
void astableFSM()
{
	int16_t delta;
	
	delta = calcDelta();
	
    bool edge = edgeDetect();
    
	switch(current_status.st)
	{
    	case eIDLE:
    	{
        	// Advance when we see the switch actuate
        	if(current_status.input == true)
        	{
            	current_status.st = eATOB;
            	current_status.rising         = true;
        	}
    	}
    	break;
    	case eATOB:
    	{
            // input goes away?  Stop where we are.
        	if(current_status.input == false)
        	{
            	current_status.st = eIDLE;
            	current_status.rising         = false;
        	}
        	else if( calcNextPhasor(delta) )
        	{
            	current_status.st = eBTOA;
            	current_status.rising         = false;
        	}
    	}
    	break;
    	case eATTOP:
    	{
        	// we shouldn't actually land here,
        	// provide proper action in case we somehow do.
        	if(current_status.input == false)
        	{
            	current_status.st = eIDLE;
            	current_status.rising         = false;
        	}
            
            // Just fall through
        	current_status.st = eBTOA;
        	current_status.rising         = false;
    	}
    	break;
    	case eBTOA:
    	{
        	// dropping down to A
        	// only quits when it gets there - ignores switch
        	if(current_status.input == false)
	        	{
    	        	current_status.st = eIDLE;
    	        	current_status.rising         = false;
	        	}
            else if( calcNextPhasor(delta) )
        	{
            	current_status.st = eATOB;
  	        	current_status.rising         = true;
        	}
    	}
    	break;
    	default:
    	{
        	// TODO: better fix?
        	// debugger catch for invalid states
        	while(1);
    	}
	}
    
    

	current_status.us_val =  scalePhasor();
	
}


// Other FSM candidates?
// monostable - like one-shot, but doesn't have to complete cycle is released before it reaches B?


// Read a given channel of ADC.
uint32_t readADC(uint8_t chan)
{
	uint32_t value;
	
	// only allow the pins we've selected to read...
	if(!( (chan == POTA_CHAN) || (chan == POTB_CHAN) || (chan == POTT_CHAN)))
	{
		return 0;
	}
	
	// turn on adc
	// TODO: perhaps turn on and leave on?
	ADCSRA = 0x86; // power bit, prescale of 64
	
	ADCSRB |= 0x10; // left justify
	
	// set digital input disable
	DIDR0 = 0x89;
	
	// input mux, vref selection
	ADMUX = chan;

	// pause a moment...
	for(volatile uint8_t i = 0xff; i != 0; i--);
	
	// bit 6 starts conversion
	// write bit 4 to clear it
	ADCSRA |= 0x50;
	//ADCSRA = 0x40;
	
	// start bit clears when complete
	while(ADCSRA & 0x40);

	value = ADCW;
	
    // Pots seem to act backwards, so reverse these readings
	return (0xffff - value);
}


/* void readInputs()

    Read the 3 pots and switch input.
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
int main(void)
{ 
	//DDRA |= 0x02;
	//PORTA |= 0x00;
	
	// Configure clock scaling.
	// 2-step procedure to keep stray pointers from mangling the value.
	// Using 16 mHz resonator, we'll divide by 2 for 8 MHz.
	CLKPR = 0x80;
	CLKPR = 0x01; // clk div 2 = 8 MHz.
	
	setupPWM();
	
	// Set up and read the solder jumpers
	// Both solder jumpers are normally-open, pulled up externally,
	// therefore grounded when closed.
	// Mode selects which FSM is used - 
	//     pulled up = bistable
	//     grounded  = monostable.
	// Polarity indicates polarity of the switch/ pulse input. 
	//     pulled up = active low or switch closure
	//     grounded  = active high, no pull.
	current_status.mode = (PINB & MODESEL_B_MASK);
	current_status.input_polarity = ( PINA & POLSEL_A_MASK);
	
	// set up input button pin
	if(current_status.input_polarity)
	{
		// Pulled up, active low.
		DDRA &= ~0x02; // PA1 as input
		PORTA |= 0x02; // pulled up
		
	}
	else
	{
		// Active high, no pull.
		DDRA &= ~0x02; // PA1 as input
	}

	// initialize global data
	current_status.input  = false;
	current_status.st     = eIDLE;
	current_status.phasor = 0;
	current_status.rising = true;

	// Read all of the inputs one before we enable the FSM,
	// so it doesn't start with invalid data.
	readInputs();

	// Turn off some peripherals that we're not using.
	PRR |= 0x06;//turn off USI and TIM0.

	// then enable interrupts
	sei();
	
    while(1)
    {
        // The real action all takes place in the PWM ISR.
        
		// Not sure how much difference this was making...maybe a couple mA?
		// We have to leave the timer running, so we can only idle...
		sleep_enable();
		set_sleep_mode(SLEEP_MODE_IDLE);
		sleep_mode();
    }
}

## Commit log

2014-07-18 Adding draft of board files
    [Servo_Trigger.brd, Servo_Trigger.sch]
2014-07-23 Redid ramp generation.
    Using constant traversal time rather than constant rate. Moved to
    higher-precision math, too.
    [trapezoids.ods]
2014-09-11 PCB Work in progress
    Routed board, set up basic jumpers.
    [Servo_Trigger.brd, Servo_Trigger.sch]
2014-09-12 PCB updates
    [Servo_Trigger.brd, Servo_Trigger.sch]
2014-09-15 Updating parts
    I'd cut & pasted the tiny programmer, which used outdated parts.
    Updated to 0603 resistors & caps, using resonator instead of crystal,
    etc.
    [Servo_Trigger.brd, Servo_Trigger.sch]
2014-10-16 Minor updates.
    Evaluating prototype - added tool-notes.txt, that detailes some of the
    hangups with the debugger & how to escape them.
    About to commence on total redo of ramp generation, this is a
    placeholder.
2014-10-20 More WIP.
    Added one-shot FSM.
    Cleaned up gratuitous magic constants.
    [Servo_Trigger.brd, Servo_Trigger.sch]
2014-10-23 Modality implemented.
    SJ1 selects between bistable and monostable modes.
    SJ2 selects between active lo (switch) and active high(logic) modes.
    Renamed "sw" pin to the more accurate "in."
    [Servo_Trigger.brd]
2014-10-23 Restructuring a bit.
    Inputs are only read at end of ISR, not constantly polled.
    Trying out low power idle mode...it doesn't make much of a difference.
    [Servo_Trigger.sch]
2014-10-24 Adding writeup to Readme, adding timing spreadsheet.
    [translation.ods]
2014-10-28 Adding some notes
    Notes about using a tiny programmer to reflash the device.
    Moved tool-notes.txt into the docs folder.
2014-10-28 Renaming the firmware.
    It was the default "GccApplication" name, now it's all "ServoTrigger"
2014-12-12 Revision from collaborator and checklists
    Added mounting holes, rearranged the interface connectors.
    [Servo_Trigger.brd, Servo_Trigger.sch]
2014-12-15 After engineering review
    PCB is ready for QC checklist.
    [SparkFun_Servo_Trigger.brd, SparkFun_Servo_Trigger.sch]
2014-12-16 Updates based on checklist
    Undoing pour under IC.
    [SparkFun_Servo_Trigger.brd, SparkFun_Servo_Trigger.sch]
2014-12-17 Adding test point off each trimpot
    As per discussion with Bryon we decided to add a test point off of each
    pot's ADC line in order to better automate production testing.
    [SparkFun_Servo_Trigger.brd, SparkFun_Servo_Trigger.sch]
2014-12-19 changed micro fids to regular size
    [SparkFun_Servo_Trigger.brd, SparkFun_Servo_Trigger.sch]
2014-12-19 created panel v10
    [SparkFun_Servo_Trigger_Panel_v10.brd]
2015-01-14 Firmware changes for CTP
    Different state machine - may or may not be the one he wants.
    [translation.ods]
2015-03-09 Adding makefile, some proofreading.
    [translation.ods, trapezoids.ods]
2015-03-09 Adding FSM comments to C source
    [translation.ods]
2015-03-27 Updating README, fixing directory names
    [SparkFun_Servo_Trigger_Panel_v10.brd]
2015-07-07 Updating description of mode jumper.
    [SparkFun_Servo_Trigger.sch]

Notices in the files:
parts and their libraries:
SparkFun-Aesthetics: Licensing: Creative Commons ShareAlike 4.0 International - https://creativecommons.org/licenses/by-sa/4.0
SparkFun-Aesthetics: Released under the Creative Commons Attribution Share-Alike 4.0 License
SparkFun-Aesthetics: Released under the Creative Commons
